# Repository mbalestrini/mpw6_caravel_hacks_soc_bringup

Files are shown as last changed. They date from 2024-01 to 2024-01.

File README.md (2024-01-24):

# mpw6_caravel_hacks_soc_bringup

## **MPW6 silicon test: Hack SoC project inside Caravel architecture**

---
### **Architecture overview:**

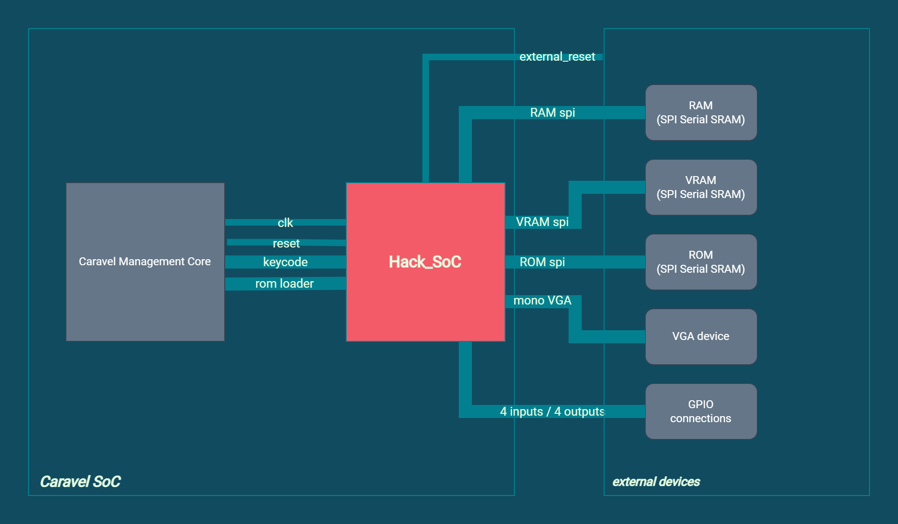
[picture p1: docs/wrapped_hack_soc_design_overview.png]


### **MPRJ_IO Connections:**

| |  | |  
|---|---|---|
|RAM_CS_N |output|MPRJ_IO[8]
|RAM_CSK |output|MPRJ_IO[9]
|RAM_SIO0 |inout|MPRJ_IO[10]
|RAM_SIO1 |inout|MPRJ_IO[11]
|RAM_SIO2 |inout|MPRJ_IO[12]
|RAM_SIO3 |inout|MPRJ_IO[13]
||||
|ROM_CS_N |output|MPRJ_IO[14]
|ROM_CSK |output|MPRJ_IO[15]
|ROM_SIO0 |inout|MPRJ_IO[16]
|ROM_SIO1 |inout|MPRJ_IO[17]
|ROM_SIO2 |inout|MPRJ_IO[18]
|ROM_SIO3 |inout|MPRJ_IO[19]
||||
|VRAM_CS_N |output|MPRJ_IO[20]
|VRAM_CSK |output|MPRJ_IO[21]
|VRAM_SIO0 |inout|MPRJ_IO[22]
|VRAM_SIO1 |inout|MPRJ_IO[23]
|VRAM_SIO2 |inout|MPRJ_IO[24]
|VRAM_SIO3 |inout|MPRJ_IO[25]
||||
|HACK_EXTERNAL_RESET|input|MPRJ_IO[26]
||||
|DISPLAY_VSYNC |output|MPRJ_IO[27]
|DISPLAY_HSYNC |output|MPRJ_IO[28]
|DISPLAY_RGB |output|MPRJ_IO[29]
||||
|GPIO_I_0|input|MPRJ_IO[30]
|GPIO_I_1|input|MPRJ_IO[31]
|GPIO_I_2|input|MPRJ_IO[32]
|GPIO_I_3|input|MPRJ_IO[33]
||||
|GPIO_O_0|output|MPRJ_IO[34]
|GPIO_O_1|output|MPRJ_IO[35]
|GPIO_O_2|output|MPRJ_IO[36]
|GPIO_O_3|output|MPRJ_IO[37]

---

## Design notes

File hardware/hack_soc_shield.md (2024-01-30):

- Correct the J2 pin alignment. On board v0.1 they didn't match with the caravel board
- Think which pins or parts we loose access if we make a stack up board that covers the caravel board: J2 serial toggle, blinking leds, reset button?
- For now leave video output as just pins (no VGA connector or driver chip). Maybe prepare some pins to do an add on board for video? 
- ~~Put some jumpers (or some switches) on the SRAM CS pin, to be able to use another device (an fpga) instead of the memory~~
- ~~Connect caravel `gpio` pin to a LED?~~
- ~~Change J2 connection on caravel board to female header and male pins on this shield board~~
- ~~Add a row of test pins or headers connected to ground~~
- ~~J2 serial toggle (I could put some female header on the bottom of the board to connect to J2). I could also add a switch to change between modes~~
- ~~Use long "double sided" male header pins to have access to all the pins for debugging or connecting other stuff~~
- Can I make the board shorter if it's just from memories? (no video output or gpio )
- ~~Connect IO[26]-HACK_EXTERNAL_RESET to a pull down and a switch~~

Future versions:
- Put VGA connector + driver + resistors
- Put LEDs for GPIOs appart from header pins?
- Think how to connect an fpga (icebreaker?) for debugging memories communication and fake programs?
- Add caravel button to caravel RST_N ? 
- PS2 keyboard to caravel connector?

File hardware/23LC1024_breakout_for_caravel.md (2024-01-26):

### 23LC1024 breakout board for caravel

- Data pins are easy because they are all togheter in caravel's header, but I need to think how would I connect PWR & GND 
- Add some header pind to be able to debug and connect the logic analyzer or the oscilloscope

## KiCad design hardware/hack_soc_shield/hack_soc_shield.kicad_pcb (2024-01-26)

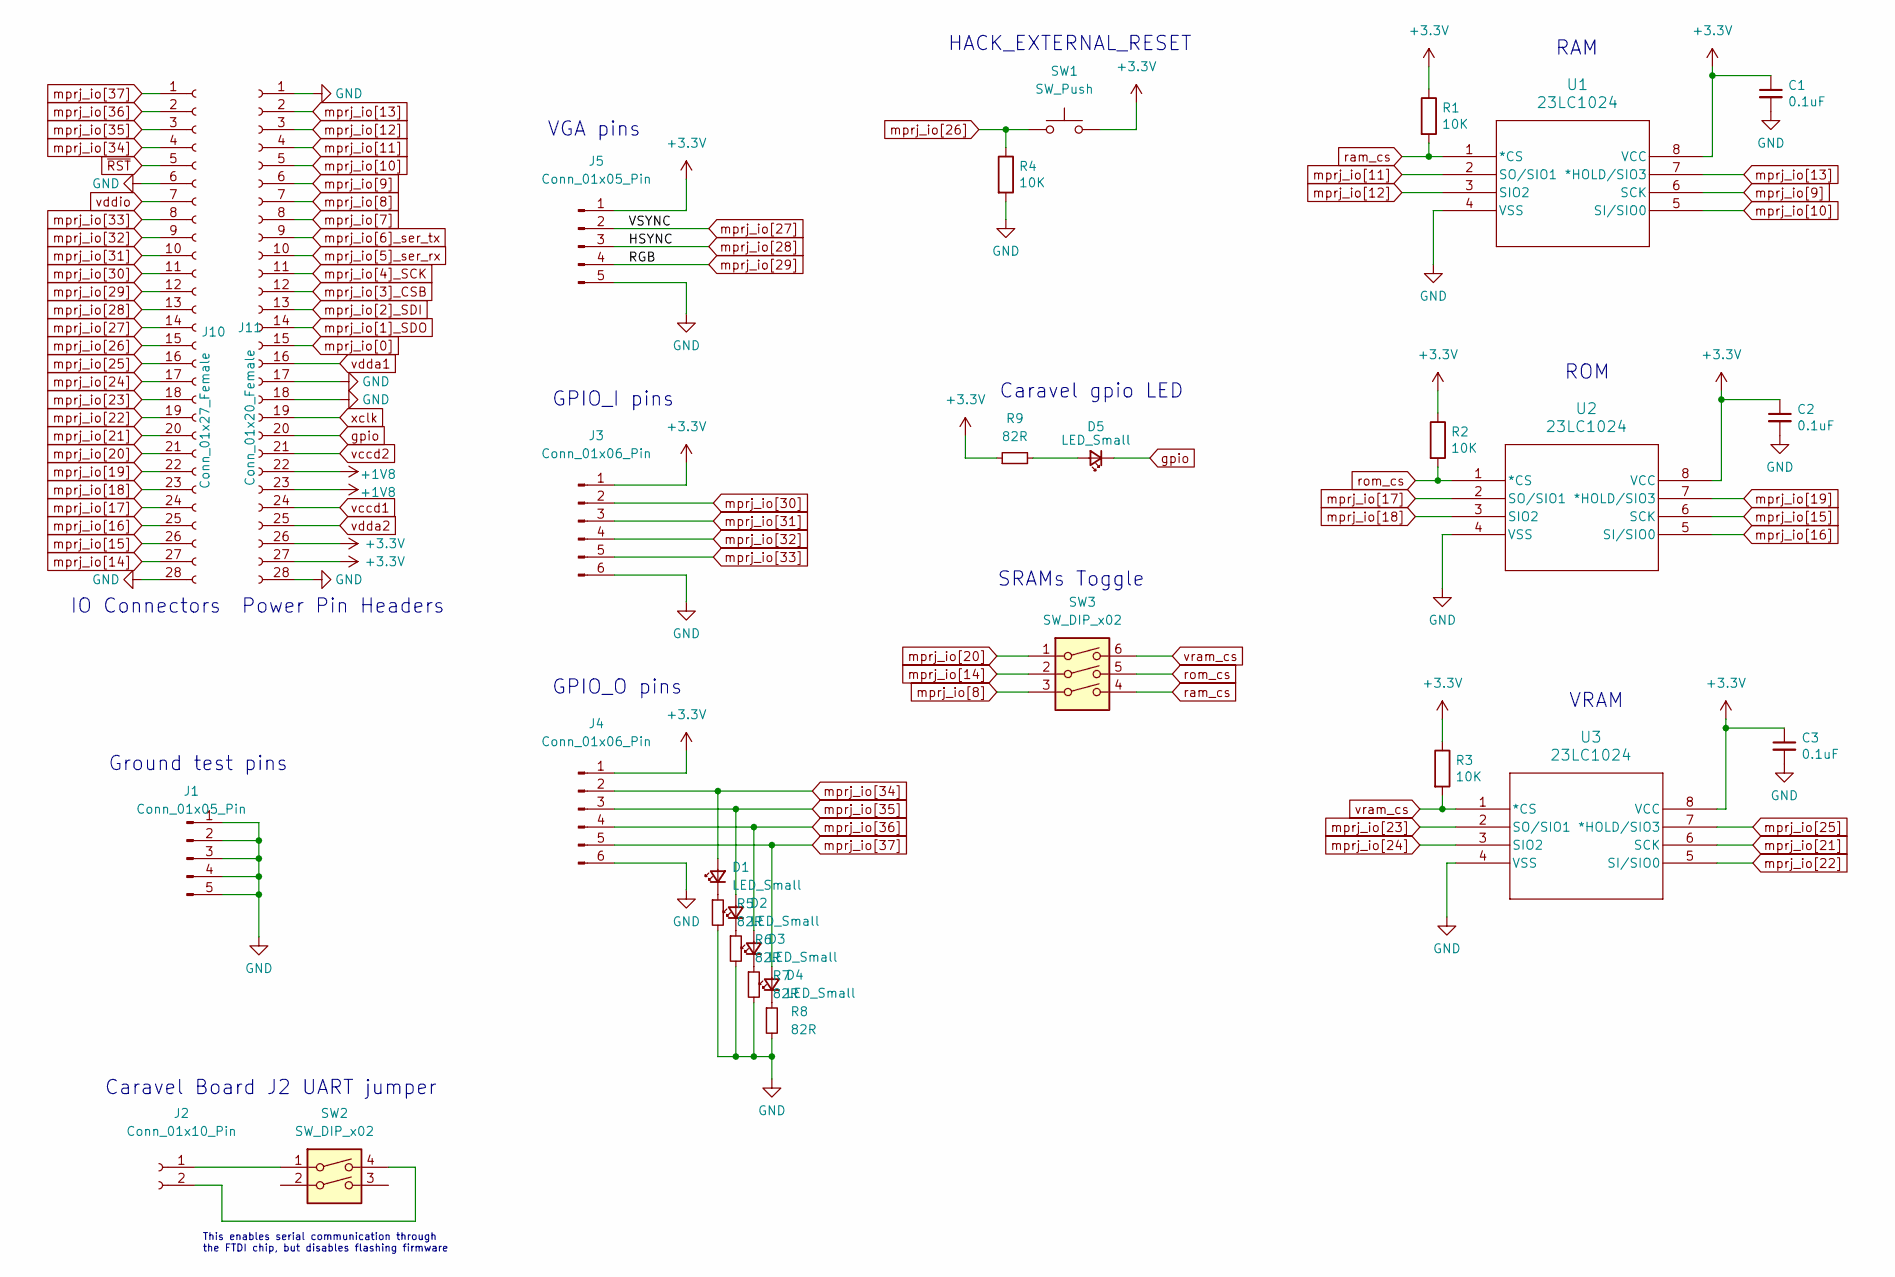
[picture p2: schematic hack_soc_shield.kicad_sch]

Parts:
C1, C2, C3: 0.1uF; C_Disc_D6.0mm_W2.5mm_P5.00mm
D1, D2, D3, D4, D5: LED_Small; LED_1206_3216Metric_Pad1.42x1.75mm_HandSolder
J1, J5: Conn_01x05_Pin; PinHeader_1x05_P2.54mm_Vertical
J2: Conn_01x10_Pin; PinHeader_1x02_P2.54mm_Vertical
J3, J4: Conn_01x06_Pin; PinHeader_1x06_P2.54mm_Vertical
J10: Conn_01x27_Female; PinHeader_1x28_P2.54mm_Vertical
J11: Conn_01x20_Female; PinHeader_1x28_P2.54mm_Vertical
R1, R2, R3, R4: 10K; R_Axial_DIN0204_L3.6mm_D1.6mm_P5.08mm_Horizontal
R5, R6, R7, R8, R9: 82R; R_1206_3216Metric_Pad1.30x1.75mm_HandSolder
SW1: SW_Push; SW_PUSH_6mm
SW2: SW_DIP_x02; SW_DIP_SPSTx02_Slide_9.78x7.26mm_W7.62mm_P2.54mm
SW3: SW_DIP_x02; SW_DIP_SPSTx03_Slide_9.78x9.8mm_W7.62mm_P2.54mm
U1, U2, U3: 23LC1024; SOIC8-N_MC_MCH

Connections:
+1V8: J11.22, J11.23
+3.3V: C1.1, C2.1, C3.1, J3.1, J4.1, J5.1, J11.26, J11.27, R1.1, R2.1, R3.1, R9.1, SW1.2, U1.8 (VCC), U2.8 (VCC), U3.8 (VCC)
GND: C1.2, C2.2, C3.2, J1.1, J1.2, J1.3, J1.4, J1.5, J5.5, J10.6, J10.28, J11.1, J11.17, J11.18, J11.28, R4.2, R5.2, R6.2, R7.2, R8.2, U1.4 (VSS), U2.4 (VSS), U3.4 (VSS)
unnamed: D1.1 (K), R5.1
unnamed: D2.1 (K), R6.1
unnamed: D3.1 (K), R7.1
unnamed: D4.1 (K), R8.1
unnamed: D5.2 (A), R9.2
unnamed: J2.1, SW2.1
unnamed: J2.2, SW2.4
gpio: D5.1 (K), J11.20
mprj_io[0]: J11.15
mprj_io[1]_SDO: J11.14
mprj_io[2]_SDI: J11.13
mprj_io[3]_CSB: J11.12
mprj_io[4]_SCK: J11.11
mprj_io[5]_ser_rx: J11.10
mprj_io[6]_ser_tx: J11.9
mprj_io[7]: J11.8
mprj_io[8]: J11.7, SW3.3
mprj_io[9]: J11.6, U1.6 (SCK)
mprj_io[10]: J11.5, U1.5 (SI/SIO0)
mprj_io[11]: J11.4, U1.2 (SO/SIO1)
mprj_io[12]: J11.3, U1.3 (SIO2)
mprj_io[13]: J11.2, U1.7 (*HOLD/SIO3)
mprj_io[14]: J10.27, SW3.2
mprj_io[15]: J10.26, U2.6 (SCK)
mprj_io[16]: J10.25, U2.5 (SI/SIO0)
mprj_io[17]: J10.24, U2.2 (SO/SIO1)
mprj_io[18]: J10.23, U2.3 (SIO2)
mprj_io[19]: J10.22, U2.7 (*HOLD/SIO3)
mprj_io[20]: J10.21, SW3.1
mprj_io[21]: J10.20, U3.6 (SCK)
mprj_io[22]: J10.19, U3.5 (SI/SIO0)
mprj_io[23]: J10.18, U3.2 (SO/SIO1)
mprj_io[24]: J10.17, U3.3 (SIO2)
mprj_io[25]: J10.16, U3.7 (*HOLD/SIO3)
mprj_io[26]: J10.15, R4.1, SW1.1
mprj_io[27]: J5.2, J10.14
mprj_io[28]: J5.3, J10.13
mprj_io[29]: J5.4, J10.12
mprj_io[30]: J3.2, J10.11
mprj_io[31]: J3.3, J10.10
mprj_io[32]: J3.4, J10.9
mprj_io[33]: J3.5, J10.8
mprj_io[34]: D1.2 (A), J4.2, J10.4
mprj_io[35]: D2.2 (A), J4.3, J10.3
mprj_io[36]: D3.2 (A), J4.4, J10.2
mprj_io[37]: D4.2 (A), J4.5, J10.1
ram_cs: R1.2, SW3.4, U1.1 (*CS)
rom_cs: R2.2, SW3.5, U2.1 (*CS)
vccd1: J11.24
vccd2: J11.21
vdda1: J11.16
vdda2: J11.25
vddio: J10.7
vram_cs: R3.2, SW3.6, U3.1 (*CS)
xclk: J11.19
~RST: J10.5

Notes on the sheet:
SRAMs Toggle
ROM
IO Connectors
Caravel gpio LED
Power Pin Headers
Caravel Board J2 UART jumper
Ground test pins
This enables serial communication through the FTDI chip, but disables flashing firmware
GPIO_I pins
VRAM
VGA pins
RAM
HACK_EXTERNAL_RESET
GPIO_O pins

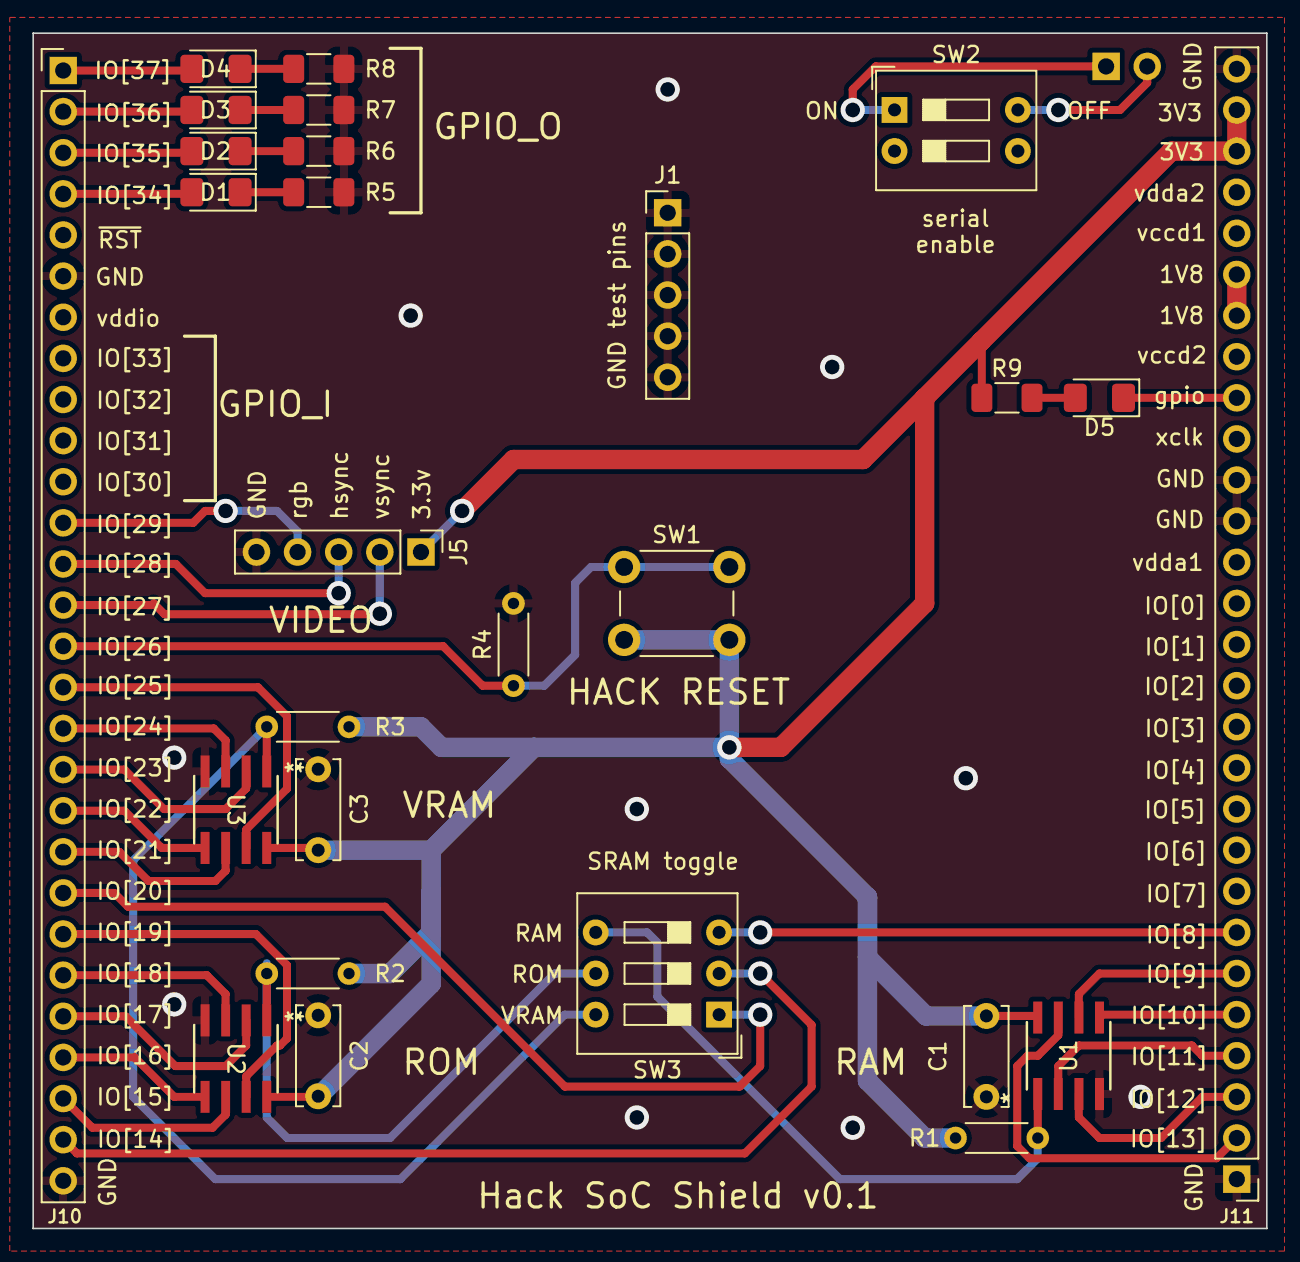
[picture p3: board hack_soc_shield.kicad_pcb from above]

Board: 2 copper layers, 76.2 x 73.8 mm, 28 parts (1 on the bottom side), 40 nets.

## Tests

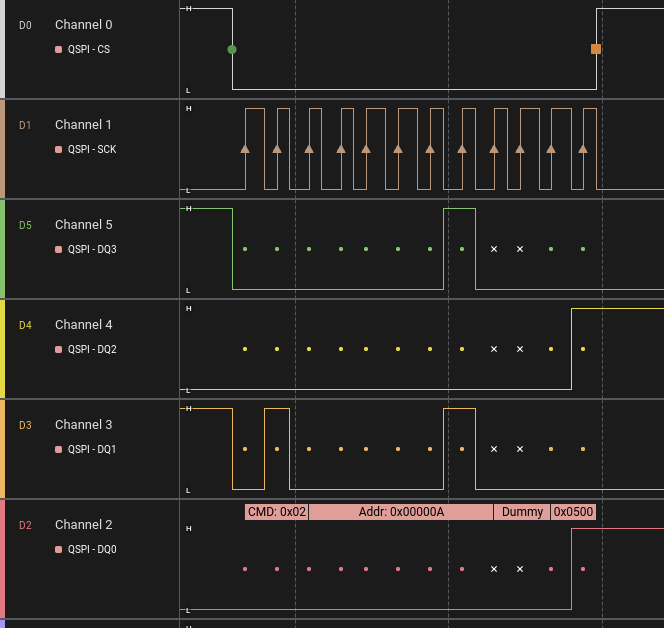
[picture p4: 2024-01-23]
devlog/mpw6_048-test_gpio_mem-3-ram_pins-20240117.png

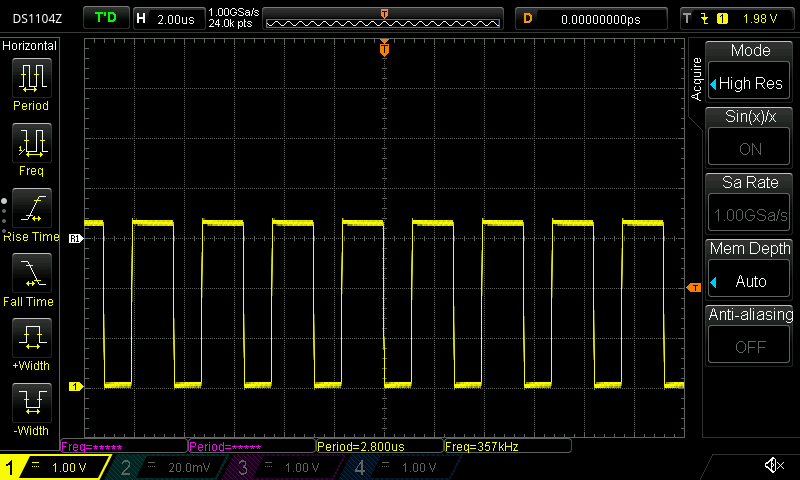
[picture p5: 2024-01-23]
devlog/mpw6_048-first_test-IO14-20231228-C.png

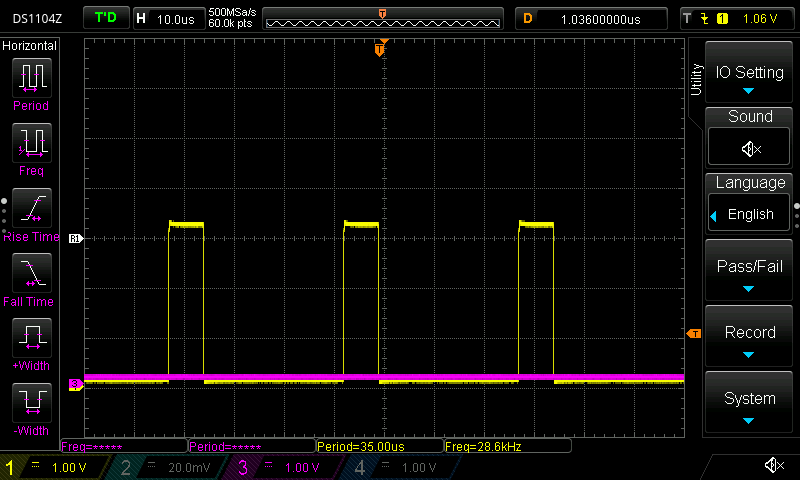
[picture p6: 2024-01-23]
devlog/mpw6_048-first_test-IO37-20231230-A.png

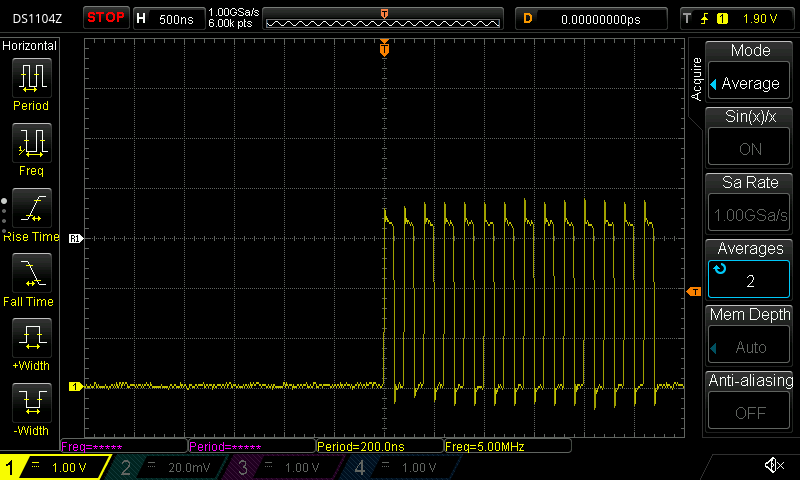
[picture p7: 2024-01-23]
devlog/mpw6_048-first_test-IO15-20231228-A.png

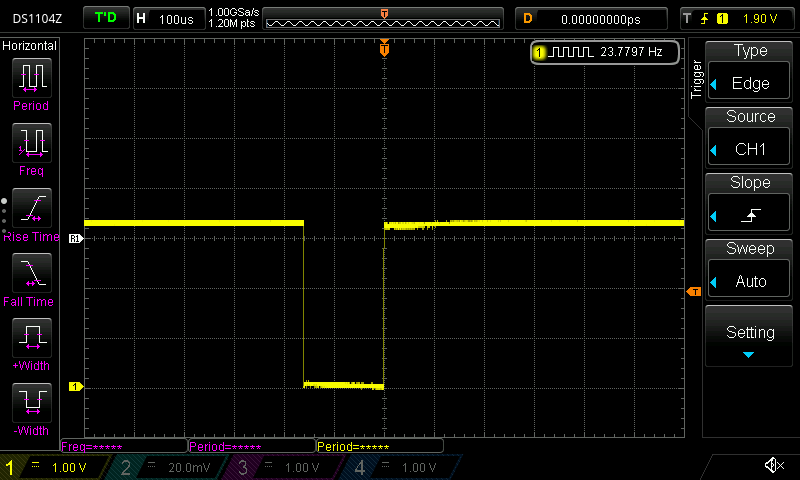
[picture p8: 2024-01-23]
devlog/mpw6_048-first_test-IO27-20231228-A.png

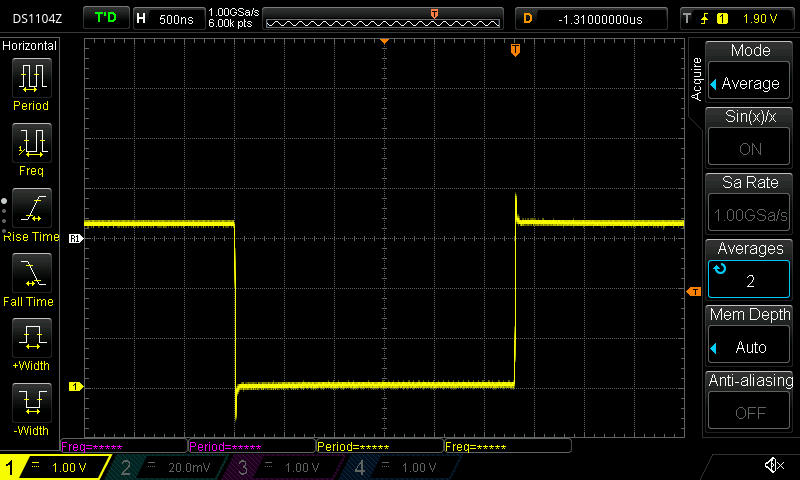
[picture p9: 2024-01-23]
devlog/mpw6_048-first_test-IO14-20231228-B.png

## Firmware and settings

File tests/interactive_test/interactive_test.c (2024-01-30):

// #include "verilog/dv/caravel/defs.h"

#define USE_DLL

#include "../defs.h"
#include "../stub.h"

#include <stdint.h>

#define ARRAY_LENGTH(x) (sizeof(x) / sizeof((x)[0]))

// #include "caravel_test_hack_program.c"
// #include "../hack_programs/beatles_by_Diogo.c"
// #include "../hack_programs/FillVram_to16390.c"
// #include "../hack_programs/test_gpio.c"
// #include "../hack_programs/test_gpio_2.c"
// #include "../hack_programs/test_gpio_mem_1.c"
// #include "../hack_programs/test_gpio_mem_2.c"
// #include "../hack_programs/PongL.c"
#include "../hack_programs/terminal2.c"

#define MULTIPROJECT_ID 11

#define RESET__LA1_BIT 0
#define KEYCODE__LA1_BIT 1
#define KEYCODE__LA1_LENGTH 8
#define ROM_LOADER_SCK__LA1_BIT 9
#define ROM_LOADER_LOAD__LA1_BIT 10
#define ROM_LOADER_DATA__LA1_BIT 11
#define ROM_LOADER_DATA__LA1_LENGTH 16
#define ROM_LOADER_ACK__LA1_BIT 27
#define HACK_EXTERNAL_RESET__LA1_BIT 28

struct logic_analyzer_t
{
	// Outputs from Pico
	uint8_t reset;
	uint8_t keycode;
	uint8_t rom_loader_sck;
	uint8_t rom_loader_load;
	uint16_t rom_loader_data;
	uint8_t hack_external_reset;
	// Inputs to Pico
	uint8_t rom_loader_ack;

} logic_analyzer;

volatile uint32_t tmp_la1_data;

void delay(const int d)
{

	/* Configure timer for a single-shot countdown */
	reg_timer0_config = 0;
	reg_timer0_data = d;
	reg_timer0_config = 1;

	// Loop, waiting for value to reach zero
	reg_timer0_update = 1; // latch current value
	while (reg_timer0_value > 0)
	{
		reg_timer0_update = 1;
	}
}

// UART code from https://github.com/efabless/caravel_mgmt_soc_litex/blob/main/verilog/dv/firmware/APIs/uart_api.h
#define UART_EV_TX 0x1
#define UART_EV_RX 0x2
/**
 * Wait receiving ASCII symbol and return it.
 *
 * Return the first ASCII symbol of the UART received queue
 *
 * RX mode have to be enabled
 *
 */
char UART_readChar()
{
	while (uart_rxempty_read() == 1)
		;
	return reg_uart_data;
}
/**
 * Pop the first ASCII symbol of the UART received queue
 *
 * UART_readChar() function would keeping reading the same symbol unless this function is called
 */
void UART_popChar()
{
	uart_ev_pending_write(UART_EV_RX);
	return;
}
/**
 * Send ASCII char through UART
 * @param c ASCII char to send
 *
 * TX mode have to be enabled
 */
void UART_sendChar(char c)
{
	while (reg_uart_txfull == 1)
		;
	reg_uart_data = c;
}
/**
 * Send int through UART
 * the int would be sent as 8 hex characters
 * @param c int to send
 *
 * TX mode have to be enabled
 */
void UART_sendInt(uint32_t data)
{
	for (int i = 0; i < 8; i++)
	{
		// Extract the current 4-bit chunk
		int chunk = (data >> (i * 4));
		if (chunk == 0)
		{
			break;
		}
		chunk = chunk & 0x0F;
		char ch;
		if (chunk >= 0 && chunk <= 9)
		{
			ch = '0' + chunk; // Convert to corresponding decimal digit character
		}
		else
		{
			ch = 'A' + (chunk - 10); // Convert to corresponding hex character A-F
		}
		UART_sendChar(ch);
	}
	UART_sendChar('\n');
}

void print_gpio_values_header() 
{
	char d0 = '0';
	char d1 = '0';

	// HEADER
	for (int32_t i = 0; i < 38; i++)
	{
		print("[");
		putchar(d1);
		putchar(d0);
		print("] ");
		d0 = d0 + 1;
		if (d0 > ('0' + 9))
		{
			d0 = '0';
			d1 = d1 + 1;
		}
	}

	print("\n");
}

void print_gpio_values()
{
	// VALUES
	for (int32_t i = 0; i < 38; i++)
	{
		uint32_t value;

		if (i < 32)
		{
			value = ((reg_mprj_datal >> i) & 0x1);
		}
		else
		{
			value = ((reg_mprj_datah >> (i - 32)) & 0x1);
		}

		print("  ");
		if (value)
		{
			print("1");
		}
		else
		{
			print("0");
		}
		print("  ");
	}
	print("\r");
}

void rom_loader()
{

	uint16_t program_size = ARRAY_LENGTH(hack_program);

	// Start ROM LOADING
	logic_analyzer.rom_loader_load = 1;
	tmp_la1_data = (tmp_la1_data & ~(1 << ROM_LOADER_LOAD__LA1_BIT)) | (logic_analyzer.rom_loader_load << ROM_LOADER_LOAD__LA1_BIT);

	for (int i = 0; i < program_size; ++i)
	{

		logic_analyzer.rom_loader_data = hack_program[i];
		tmp_la1_data = (tmp_la1_data & ~(0xffff << ROM_LOADER_DATA__LA1_BIT)) | (logic_analyzer.rom_loader_data << ROM_LOADER_DATA__LA1_BIT);
		logic_analyzer.rom_loader_sck = 1;
		tmp_la1_data = (tmp_la1_data & ~(1 << ROM_LOADER_SCK__LA1_BIT)) | (logic_analyzer.rom_loader_sck << ROM_LOADER_SCK__LA1_BIT);
		reg_la1_data = tmp_la1_data;

		// TODO: Here I need to wait for the ACK. Without it only works if the code is slow enough for the HACK_SOC to process it before changing the rom_loader_sck line
		// But right now the ACK signal it lasts only one clock, so it might be hard to get. I should change that in the rtl

		logic_analyzer.rom_loader_sck = 0;
		tmp_la1_data = (tmp_la1_data & ~(1 << ROM_LOADER_SCK__LA1_BIT)) | (logic_analyzer.rom_loader_sck << ROM_LOADER_SCK__LA1_BIT);
		reg_la1_data = tmp_la1_data;
	}

	// Finished ROM LOADING
	logic_analyzer.rom_loader_load = 0;
	tmp_la1_data = (tmp_la1_data & ~(1 << ROM_LOADER_LOAD__LA1_BIT)) | (logic_analyzer.rom_loader_load << ROM_LOADER_LOAD__LA1_BIT);
	reg_la1_data = tmp_la1_data;
}

void main()
{
	/*
	IO Control Registers
	| DM     | VTRIP | SLOW  | AN_POL | AN_SEL | AN_EN | MOD_SEL | INP_DIS | HOLDH | OEB_N | MGMT_EN |
	| 3-bits | 1-bit | 1-bit | 1-bit  | 1-bit  | 1-bit | 1-bit   | 1-bit   | 1-bit | 1-bit | 1-bit   |

	Output: 0000_0110_0000_1110  (0x1808) = GPIO_MODE_USER_STD_OUTPUT
	| DM     | VTRIP | SLOW  | AN_POL | AN_SEL | AN_EN | MOD_SEL | INP_DIS | HOLDH | OEB_N | MGMT_EN |
	| 110    | 0     | 0     | 0      | 0      | 0     | 0       | 1       | 0     | 0     | 0       |


	Input: 0000_0001_0000_1111 (0x0402) = GPIO_MODE_USER_STD_INPUT_NOPULL
	| DM     | VTRIP | SLOW  | AN_POL | AN_SEL | AN_EN | MOD_SEL | INP_DIS | HOLDH | OEB_N | MGMT_EN |
	| 001    | 0     | 0     | 0      | 0      | 0     | 0       | 0       | 0     | 1     | 0       |

	*/

	// ** HACK GPIO ** //
	// gpio_o
	reg_mprj_io_37 = GPIO_MODE_USER_STD_OUTPUT;
	reg_mprj_io_36 = GPIO_MODE_USER_STD_OUTPUT;
	reg_mprj_io_35 = GPIO_MODE_USER_STD_OUTPUT;
	reg_mprj_io_34 = GPIO_MODE_USER_STD_OUTPUT;

	// gpio_i
	reg_mprj_io_33 = GPIO_MODE_USER_STD_INPUT_NOPULL;
	reg_mprj_io_32 = GPIO_MODE_USER_STD_INPUT_NOPULL;
	reg_mprj_io_31 = GPIO_MODE_USER_STD_INPUT_NOPULL;
	reg_mprj_io_30 = GPIO_MODE_USER_STD_INPUT_NOPULL;

	// ** DISPLAY VSYNC< HSYNC, RGB ** //
	// rgb
	reg_mprj_io_29 = GPIO_MODE_USER_STD_OUTPUT;
	// hsync
	reg_mprj_io_28 = GPIO_MODE_USER_STD_OUTPUT;
	// vsync
	reg_mprj_io_27 = GPIO_MODE_USER_STD_OUTPUT;

	//	** HACK_EXTERNAL_RESET ** //
	reg_mprj_io_26 = GPIO_MODE_USER_STD_INPUT_NOPULL;

	//	** VRAM ** //

	// SPI VRAM SIO
	reg_mprj_io_25 = GPIO_MODE_USER_STD_BIDIRECTIONAL;
	reg_mprj_io_24 = GPIO_MODE_USER_STD_BIDIRECTIONAL;
	reg_mprj_io_23 = GPIO_MODE_USER_STD_BIDIRECTIONAL;
	reg_mprj_io_22 = GPIO_MODE_USER_STD_BIDIRECTIONAL;
	// SPI VRAM_SCK
	reg_mprj_io_21 = GPIO_MODE_USER_STD_OUTPUT;
	// SPI VRAM_CS_N
	reg_mprj_io_20 = GPIO_MODE_USER_STD_OUTPUT;

	// 	** ROM ** //

	// SPI ROM SIO
	reg_mprj_io_19 = GPIO_MODE_USER_STD_BIDIRECTIONAL;
	reg_mprj_io_18 = GPIO_MODE_USER_STD_BIDIRECTIONAL;
	reg_mprj_io_17 = GPIO_MODE_USER_STD_BIDIRECTIONAL;
	reg_mprj_io_16 = GPIO_MODE_USER_STD_BIDIRECTIONAL;
	// SPI ROM_SCK
	reg_mprj_io_15 = GPIO_MODE_USER_STD_OUTPUT;
	// SPI ROM_CS_N
	reg_mprj_io_14 = GPIO_MODE_USER_STD_OUTPUT;

	//	** RAM ** //

	// SPI RAM SIO
	reg_mprj_io_13 = GPIO_MODE_USER_STD_BIDIRECTIONAL;
	reg_mprj_io_12 = GPIO_MODE_USER_STD_BIDIRECTIONAL;
	reg_mprj_io_11 = GPIO_MODE_USER_STD_BIDIRECTIONAL;
	reg_mprj_io_10 = GPIO_MODE_USER_STD_BIDIRECTIONAL;
	// SPI RAM_SCK
	reg_mprj_io_9 = GPIO_MODE_USER_STD_OUTPUT;
	// SPI RAM_CS_N
	reg_mprj_io_8 = GPIO_MODE_USER_STD_OUTPUT;

	reg_mprj_io_5 = GPIO_MODE_MGMT_STD_INPUT_NOPULL; // UART Rx
	reg_mprj_io_6 = GPIO_MODE_MGMT_STD_OUTPUT;		 // UART Tx

	/* Apply configuration */
	reg_mprj_xfer = 1;
	while (reg_mprj_xfer == 1)
		;

	// Default value for LA[31:0] = OUTPUT
	reg_la1_oenb = reg_la1_iena = 0xFFFFFFFF;
// reg_la1_iena = 0;

// DLL mode:
// main_clock_freq = EXTERNAL_CLOCK * reg_hkspi_pll_divider[4:0] / reg_hkspi_pll_source[2:0]
// secondary_clock_freq = EXTERNAL_CLOCK * reg_hkspi_pll_divider[4:0] / reg_hkspi_pll_source[5:3]
// In this case:
// 10MHz * 10 / 4 = 25MHz
// More info: https://caravel-harness.readthedocs.io/en/latest/housekeeping-spi.html#housekeeping-reg-pll-trim
#ifdef USE_DLL
	reg_hkspi_pll_ena = 1;
	reg_hkspi_pll_source = 0x04;
	reg_hkspi_pll_divider = 0x0a;
	// reg_hkspi_pll_trim = 0;
	reg_hkspi_pll_bypass = 0;
#endif

	// rom_loader_ack is input
	// reg_la1_iena  = reg_la1_oenb  = ~( 1<< ROM_LOADER_ACK__LA1_BIT );
	reg_la1_iena = reg_la1_oenb = (reg_la1_oenb & ~(1 << ROM_LOADER_ACK__LA1_BIT));
	// reg_la1_iena = reg_la1_iena | ( 1<< ROM_LOADER_ACK__LA1_BIT );

	// Setup UART and MGMT GPIO pin for debugging purposes
	reg_uart_enable = 1;

	reg_gpio_mode1 = 1;
	reg_gpio_mode0 = 0;
	reg_gpio_ien = 1;
	reg_gpio_oe = 0;

	print("Starting HackSoC\n");

	delay(5000000);

	char c;
	c = UART_readChar();
	UART_popChar();
	print("Read:");
	putchar(c);
	print("\n");

	// c = UART_readChar();
	// UART_popChar();
	// print("Read:");
	// putchar(c);
	// print("\n");

	// system reset
	logic_analyzer.reset = 1;
	logic_analyzer.keycode = 97;
	logic_analyzer.rom_loader_load = 0;
	// hack_cpu reset
	logic_analyzer.hack_external_reset = 1;
	// logic_analyzer.rom_loader_sck = 0;
	// logic_analyzer.rom_loader_data = 0;

	// Set initial output values
	tmp_la1_data = (logic_analyzer.reset << RESET__LA1_BIT) |
				   (logic_analyzer.keycode << KEYCODE__LA1_BIT) |
				   (logic_analyzer.rom_loader_load << ROM_LOADER_LOAD__LA1_BIT) |
				   (logic_analyzer.hack_external_reset << HACK_EXTERNAL_RESET__LA1_BIT);
	;
	// (logic_analyzer.rom_loader_sck << 9) |
	// (logic_analyzer.rom_loader_data << 11);
	reg_la1_data = tmp_la1_data;

	// activate the project by setting the [project ID] bit of 2nd bank of LA
	reg_la0_iena = 0xFFFFFFFF; // input enable off
	reg_la0_oenb = 0xFFFFFFFF; // output enable on
	reg_la0_data = 1 << MULTIPROJECT_ID;

	// Release system reset
	logic_analyzer.reset = 0;
	tmp_la1_data = (tmp_la1_data & ~(1 << RESET__LA1_BIT)) | (logic_analyzer.reset << RESET__LA1_BIT);
	reg_la1_data = tmp_la1_data;

	c = UART_readChar();
	UART_popChar();
	print("Read:");
	putchar(c);
	print("\n");

	rom_loader();

	c = UART_readChar();
	UART_popChar();
	print("Read:");
	putchar(c);
	print("\n");

	logic_analyzer.hack_external_reset = 0;
	tmp_la1_data = (tmp_la1_data & ~(1 << HACK_EXTERNAL_RESET__LA1_BIT)) | (logic_analyzer.hack_external_reset << HACK_EXTERNAL_RESET__LA1_BIT);
	reg_la1_data = tmp_la1_data;

	// reg_gpio_mode1 = 1;
	// reg_gpio_mode0 = 0;

	reg_gpio_ien = 0;
	reg_gpio_oe = 1;

	print_gpio_values_header();

	while (1)
	{
		// Blink
		reg_gpio_out = 1; // OFF
		delay(5000000);
		reg_gpio_out = 0; // ON
		delay(5000000);

		print_gpio_values();
	}
}

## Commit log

2024-01-26 Add hardware folder
    [hack_soc_shield.kicad_pcb, hack_soc_shield.kicad_sch]
2024-01-26 Update hack_soc_shield
    [hack_soc_shield.kicad_pcb, hack_soc_shield.kicad_sch]
2024-01-26 Update hardware
    [hack_soc_shield-B_Cu.gbr, hack_soc_shield-B_Mask.gbr, hack_soc_shield-Edge_Cuts.gbr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]
